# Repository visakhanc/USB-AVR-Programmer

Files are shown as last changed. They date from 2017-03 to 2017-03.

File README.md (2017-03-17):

USB AVR Programmer
==================

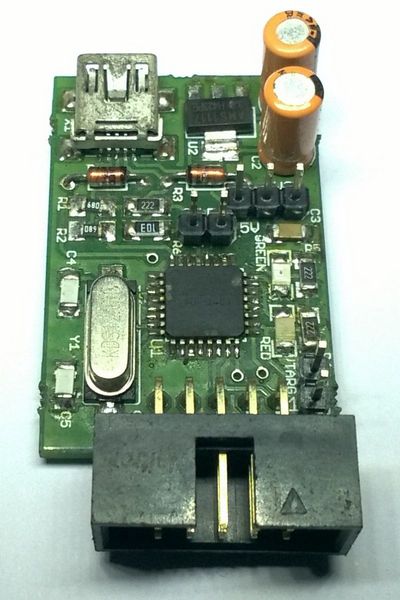
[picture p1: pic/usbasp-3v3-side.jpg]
USBASP 3.3V version


USB AVR programmer PCB and firmware files. There is Eagle PCB files for two versions: One with 5V target voltage only, other with selectable 3.3V and 5V target supply voltage. There is also a single side PCB layout image, which is meant for homemade PCB making.

For flashing the firmware, use another AVR ISP programmer connected to the ISP socket. Read the instruction in the firmware folder.

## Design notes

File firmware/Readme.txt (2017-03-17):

Instructions for flashing the firmware
--------------------------------------
1. Connect Another USBASP programmer to the ISP socket
2. Close both self programming(SELF) jumper and Target supply (VTARG) jumper. Also close the VTARG jumper of the other programmer.
3. Make sure AVR-GCC is installed (or WinAVR)
4. Go to firmware directory in the command line, type: make usbasp

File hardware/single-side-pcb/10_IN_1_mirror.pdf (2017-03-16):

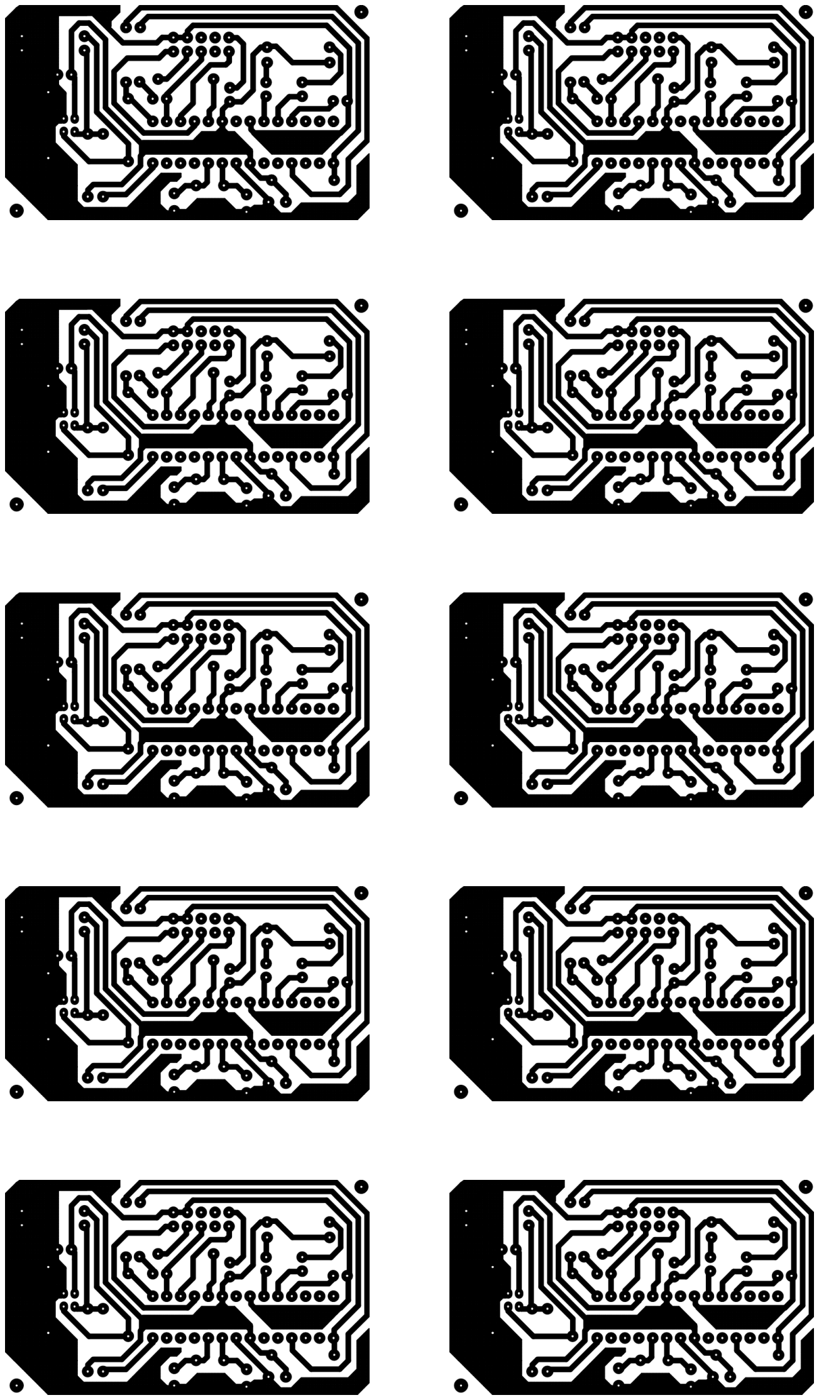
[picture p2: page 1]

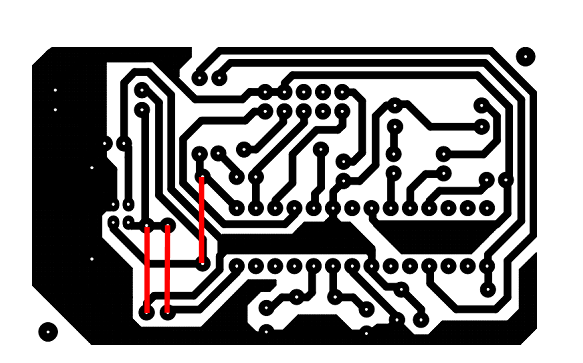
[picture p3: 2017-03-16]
hardware/single-side-pcb/Jumper Connections.png

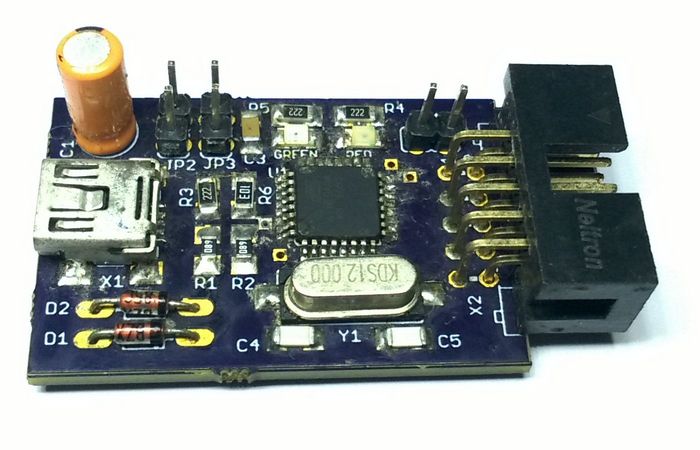
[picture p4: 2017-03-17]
pic/usbasp-side.jpg

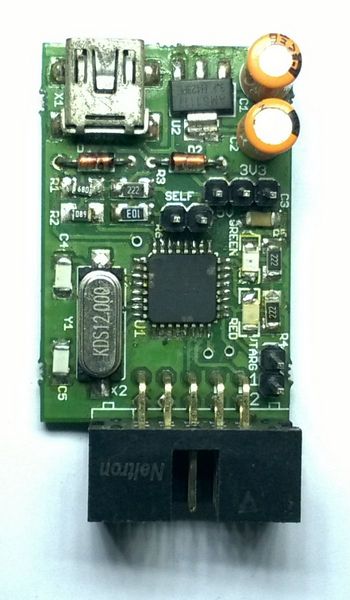
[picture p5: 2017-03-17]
pic/usbasp-3v3-top.jpg

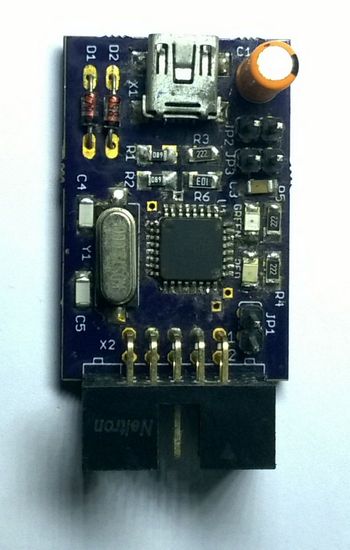
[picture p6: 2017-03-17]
pic/usbasp-top.jpg

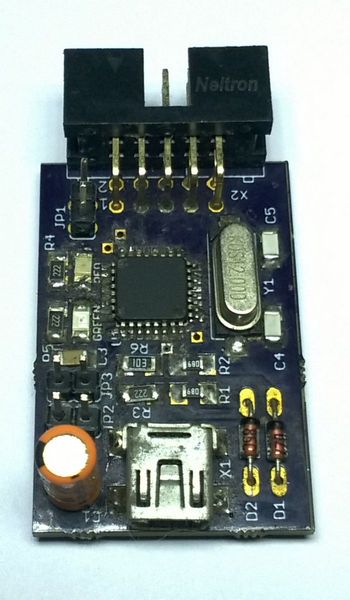
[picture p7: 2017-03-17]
pic/usbasp-side-2.jpg

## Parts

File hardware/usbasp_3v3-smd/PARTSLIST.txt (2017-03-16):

Partlist

Exported from USBasp_SMD.brd at 13-Dec-15 10:19 AM

EAGLE Version 7.5.0 Copyright (c) 1988-2015 CadSoft

Assembly variant: 

Part     Value            Package     Library               Position (inch)       Orientation

C1       4u7              E2,5-5      rcl                   (0.13 0.885)          R90
C2       22uF             E2,5-5      rcl                   (0.345 0.885)         R90
C3       100n             C1206       rcl                   (0.695 0.875)         R90
C4       22p              C1206       rcl                   (0.93 0.085)          R180
C5       22p              C1206       rcl                   (1.275 0.08)          R0
D1       3V6              DIODE-ZENER SparkFun-DiscreteSemi (0.48 0.21)           R270
D2       3V6              DIODE-ZENER SparkFun-DiscreteSemi (0.48 0.575)          R90
GREEN    green            LED-1206    SparkFun-LED          (0.86 0.83)           R0
JP1      3V3_SEL          1X03        SparkFun-Connectors   (0.585 0.895)         R270
R1       68               M1206       rcl                   (0.58 0.16)           R270
R2       68               M1206       rcl                   (0.68 0.16)           R90
R3       2k2              M1206       rcl                   (0.58 0.36)           R90
R4       1k               M1206       rcl                   (1.07 0.925)          R0
R5       1k               M1206       rcl                   (0.86 0.925)          R180
R6       10k              M1206       rcl                   (0.68 0.36)           R90
RED      red              LED-1206    SparkFun-LED          (1.075 0.83)          R180
SELF     Self Programming 1X02        SparkFun-Connectors   (0.69 0.525)          R90
U1       MEGA8-AI         TQFP32-08   atmel                 (0.975 0.56)          R90
U2       LM1117           SOT223      SparkFun-PowerIC      (0.22 0.635)          R270
VTARG    Supply Target    1X02        SparkFun-Connectors   (1.25 0.92)           R0
X1       USBSMD           USB-MINIB   SparkFun-Connectors   (0.235 0.25)          R0
X2       ISP              ML10L       con-harting-ml        (1.385 0.6)           R270
Y1       12MHz            HC49UP      SparkFun-FreqCtrl     (1.12 0.235)          R180

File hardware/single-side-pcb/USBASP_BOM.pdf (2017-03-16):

Bill Of Materials | December 2,2012 | 10:48:11 Page1
Item | Quantity | Reference | Part
______________________________________________
1 | 2 | C1,C2 | 22pF(ceramic disc)
2 | 1 | C3 | 0.1uF(ceramic disc)
3 | 1 | C4 | 4.7uF, 16V
4 | 1 | D1 | LED(RED)
5 | 1 | D2 | LED(GREEN)
6 | 2 | D4,D3 | 3.6V Zener Diode | '
7 | 3 | JP1,JP2,JP3 | 2-pin Jumper Cap
10 | 1 | R1 | 10k (1/4W)
11 | 2 | R4,R3 | 68R (1/4W)
12 | 1 | R5 | 2.2k (1/4W)
13 | 2 | R6,R7 | 1k (1/4W)
14 | 1 | U1 | ATMEGA8L/
| | | ATMEGA8A
15 | 1 | X1 | 5x2 Box Connector(Male)
16 | 1 | X2 | USB B-Type(Female)
17 | 1 | Y1 | 12 MHz Quartz Crystal

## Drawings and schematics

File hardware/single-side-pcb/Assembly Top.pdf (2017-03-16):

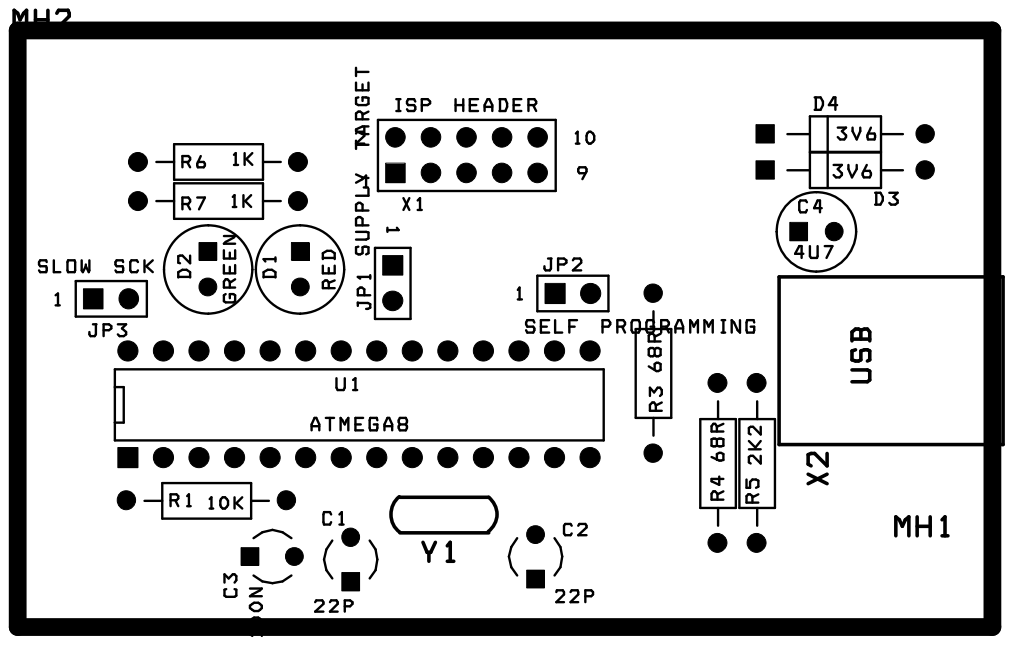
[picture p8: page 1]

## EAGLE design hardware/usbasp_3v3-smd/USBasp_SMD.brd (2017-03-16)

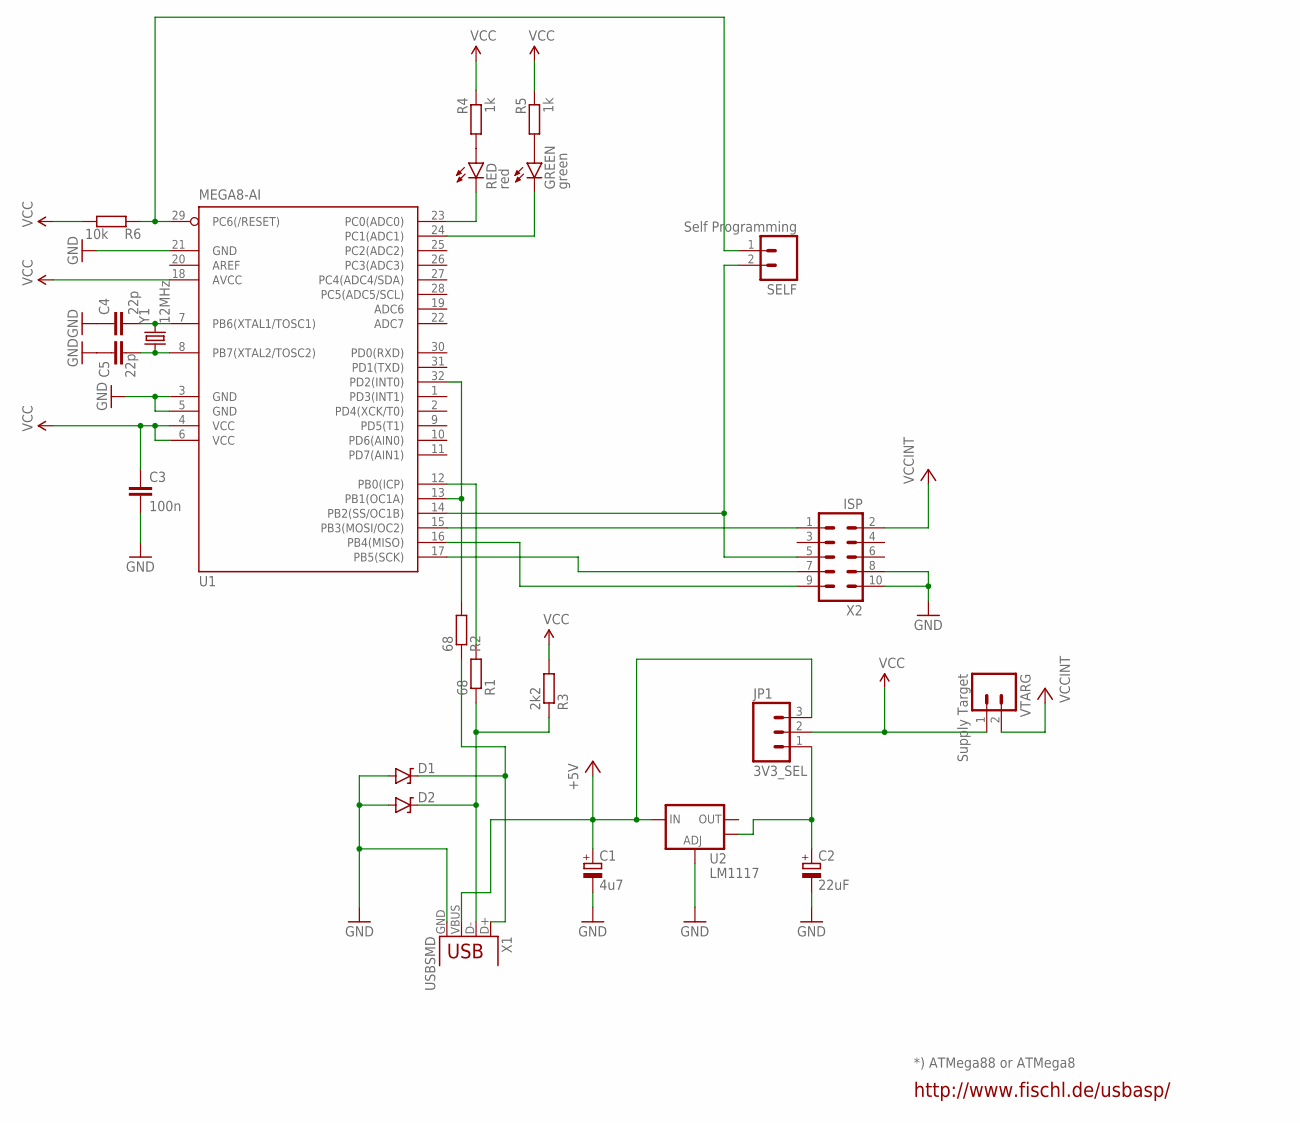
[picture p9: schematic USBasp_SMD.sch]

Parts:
C1: 4u7; E2,5-5
C2: 22uF; E2,5-5
C3: 100n; C1206
C4, C5: 22p; C1206
D1, D2: 3V6; DIODE-ZENER
GREEN: green; LED-1206
JP1: 3V3_SEL; 1X03
R1, R2: 68; M1206
R3: 2k2; M1206
R4, R5: 1k; M1206
R6: 10k; M1206
RED: red; LED-1206
SELF: Self Programming; 1X02
U1: MEGA8-AI; TQFP32-08
U2: LM1117; SOT223
VTARG: Supply Target; 1X02
X1: USBSMD; USB-MINIB
X2: ISP; ML10L
Y1: 12MHz; HC49UP

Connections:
+5V: C1.+, JP1.3, U2.3 (IN), X1.VBUS
GND: C1.-, C2.-, C3.2, C4.1, C5.1, D1.P$2 (A), D2.P$2 (A), U1.3 (GND), U1.5 (GND), U1.21 (GND), U2.1 (ADJ), X1.GND, X2.8, X2.10
unnamed: R6.2, SELF.1, U1.29 (PC6(/RESET))
unnamed: SELF.2, U1.14 (PB2(SS/OC1B)), X2.5
unnamed: U1.15 (PB3(MOSI/OC2)), X2.1
unnamed: U1.17 (PB5(SCK)), X2.7
unnamed: D2.P$1 (C), R1.1, R3.1, X1.D-
unnamed: U1.16 (PB4(MISO)), X2.9
unnamed: D1.P$1 (C), R2.1, X1.D+
unnamed: C2.+, JP1.1, U2.4 (OUT)
unnamed: R2.2, U1.13 (PB1(OC1A)), U1.32 (PD2(INT0))
unnamed: R1.2, U1.12 (PB0(ICP))
unnamed: R4.2, RED.A
unnamed: RED.C, U1.23 (PC0(ADC0))
unnamed: GREEN.C, U1.24 (PC1(ADC1))
unnamed: C4.2, U1.7 (PB6(XTAL1/TOSC1)), Y1.2
unnamed: C5.2, U1.8 (PB7(XTAL2/TOSC2)), Y1.1
unnamed: GREEN.A, R5.2
VCC: C3.1, JP1.2, R3.2, R4.1, R5.1, R6.1, U1.4 (VCC), U1.6 (VCC), U1.18 (AVCC), VTARG.1
VCCINT: VTARG.2, X2.2

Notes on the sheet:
http://www.fischl.de/usbasp/
*) ATMega88 or ATMega8

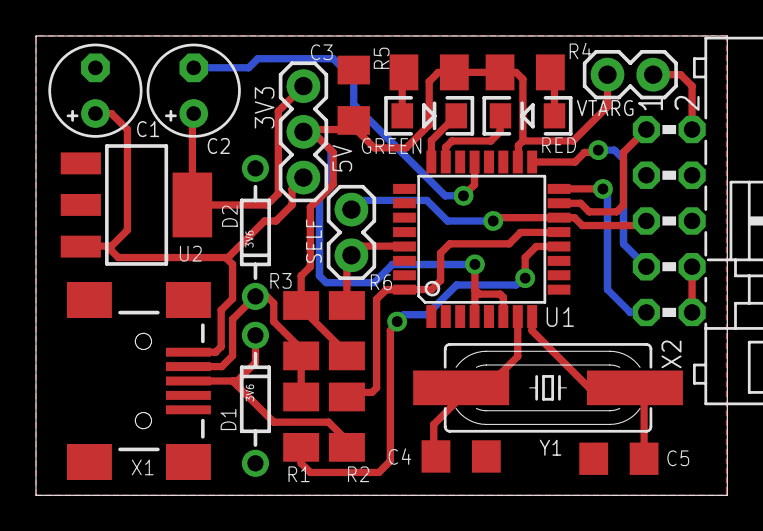
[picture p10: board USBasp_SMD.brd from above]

Board: 2 copper layers, 38.4 x 25.5 mm, 23 parts (0 on the bottom side), 20 nets.

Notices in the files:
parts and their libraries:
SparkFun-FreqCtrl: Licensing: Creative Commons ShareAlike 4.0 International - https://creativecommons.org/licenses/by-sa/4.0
